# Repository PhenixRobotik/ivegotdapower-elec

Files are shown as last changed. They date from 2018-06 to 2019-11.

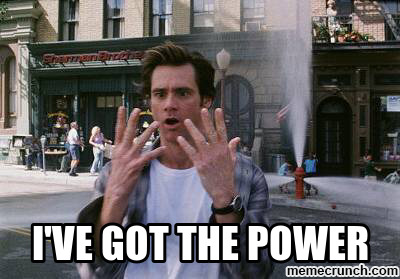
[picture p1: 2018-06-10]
ivegotdapower.jpg

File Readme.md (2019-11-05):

# IveGotDaPower, dépôt électronique

Carte alimentation de PhenixRobotik pour la base roulante TheySeeMeRolling.

<div class="alert alert-warning">
    #This project requires KiCAD 5.0 and is not compatible with previous versions (software and libraries).
</div>

# Features

* Dual power input with no-cut switch
  * Battery 6S (24V max)
  * Power supply

* Multiple power outputs
  * Power (direct, 6A)
  * Elec (7.5V ~3A)
  * USB (for Rpi, 2A)
  * …

* Voltage + current instrumentations

* CAN bus

# Idées

* stm32f3
* LiPoBipper (équilibrage) ? (ou direct sur la batterie == plus safe ?)

* Bouton d'arrêt d'urgence qui coupe la puissance moteurs ?

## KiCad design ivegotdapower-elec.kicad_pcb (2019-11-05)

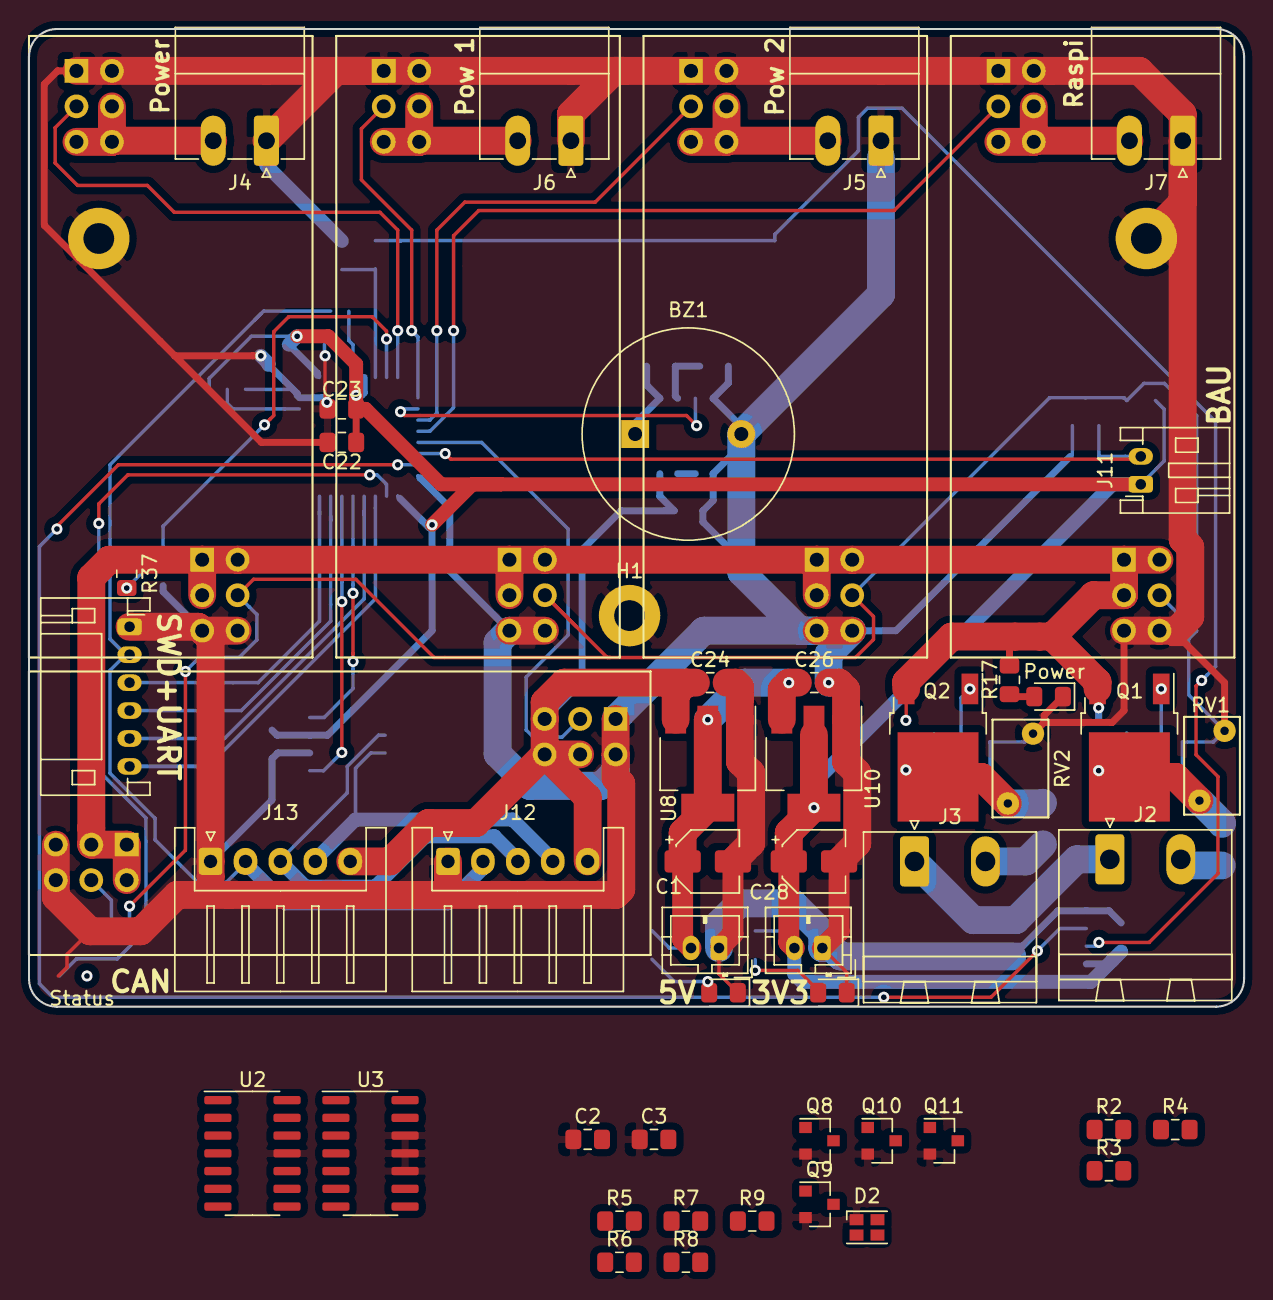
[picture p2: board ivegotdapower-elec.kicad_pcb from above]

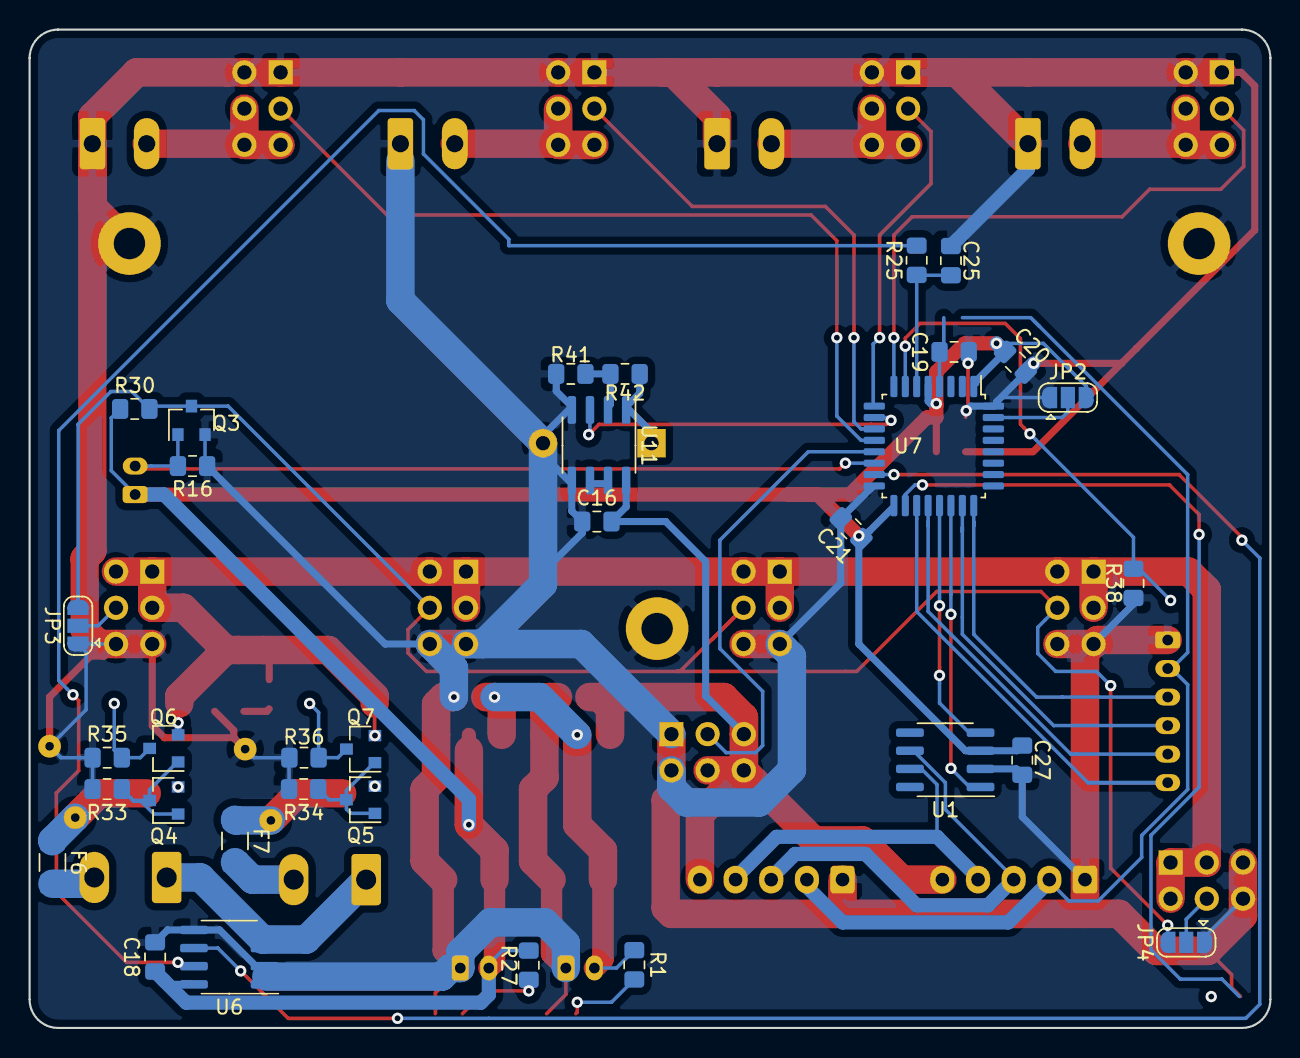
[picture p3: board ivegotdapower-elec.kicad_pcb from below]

Board: 2 copper layers, 87.0 x 70.0 mm, 88 parts (33 on the bottom side), 66 nets.

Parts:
B1, B2, B3, B4, B5: board_fille
BZ1: Buzzer; Buzzer_15x7.5RM7.6
C1, C28: 10uF; CP_Elec_4x5.4
C2, C3, C16, C18, C19, C20, C21, C23, C24, C25, C26, C27: 100nF; C_0805_2012Metric_Pad1.15x1.40mm_HandSolder
C22: 4.7uF; C_0805_2012Metric_Pad1.15x1.40mm_HandSolder
D1, D12, D16: LED; LED_0805_2012Metric_Pad1.15x1.40mm_HandSolder
D2: LED_ARGB; LED_Cree-PLCC4_2x2mm_CW
F6, F7: Fuse; Fuse_1206_3216Metric_Pad1.42x1.75mm_HandSolder
H1, H2, H3: MountingHole_Pad; MountingHole_2.2mm_M2_Pad
J1: Conn_Debug; JST_PH_S6B-PH-K_1x06_P2.00mm_Horizontal
J2: Conn_batt; PhoenixContact_MSTBA_2,5_2-G-5,08_1x02_P5.08mm_Horizontal
J3: Conn_alim; PhoenixContact_MSTBA_2,5_2-G-5,08_1x02_P5.08mm_Horizontal
J4: Conn_TSMR; PhoenixContact_MC_1,5_2-G-3.81_1x02_P3.81mm_Horizontal
J5: Conn_POW2; PhoenixContact_MC_1,5_2-G-3.81_1x02_P3.81mm_Horizontal
J6: Conn_POW1; PhoenixContact_MC_1,5_2-G-3.81_1x02_P3.81mm_Horizontal
J7: Conn_RPi; PhoenixContact_MC_1,5_2-G-3.81_1x02_P3.81mm_Horizontal
J8: Conn_+5V; JST_PH_B2B-PH-K_1x02_P2.00mm_Vertical
J10: Conn_+3.3V; JST_PH_B2B-PH-K_1x02_P2.00mm_Vertical
J11: Conn_bau; JST_PH_S2B-PH-K_1x02_P2.00mm_Horizontal
J12, J13: CAN_conn; JST_XH_S05B-XH-A_1x05_P2.50mm_Horizontal
JP2, JP3, JP4: Jumper_NC_Dual; SolderJumper-3_P1.3mm_Open_RoundedPad1.0x1.5mm
Q1, Q2: IRFR5305; TO-252-2
Q3, Q8, Q9, Q10, Q11: BSS138; SOT-23
Q4, Q5, Q6, Q7: MMBT2907A; SOT-23
R1, R17, R25, R27, R30, R33, R34, R35, R36, R41, R42: R; R_0805_2012Metric_Pad1.15x1.40mm_HandSolder
R2: 91; R_0805_2012Metric_Pad1.15x1.40mm_HandSolder
R3: 27; R_0805_2012Metric_Pad1.15x1.40mm_HandSolder
R4: 39; R_0805_2012Metric_Pad1.15x1.40mm_HandSolder
R5, R6, R7, R8, R9: 10k; R_0805_2012Metric_Pad1.15x1.40mm_HandSolder
R16: 1k; R_0805_2012Metric_Pad1.15x1.40mm_HandSolder
R37: 75k; R_0805_2012Metric_Pad1.15x1.40mm_HandSolder
R38: 15k; R_0805_2012Metric_Pad1.15x1.40mm_HandSolder
RV1, RV2: Varistor; RV_Disc_D7mm_W4mm_P5mm
U1: TCAN332; SOIC-8_3.9x4.9mm_P1.27mm
U2, U3: LM324; SOIC-14_3.9x8.7mm_P1.27mm
U6: ACS711xLCTR-12AB; SOIC-8_3.9x4.9mm_P1.27mm
U7: STM32F303K8Tx; LQFP-32_7x7mm_P0.8mm
U8: LD1117S50TR; SOT-223-3_TabPin2
U10: LD1117S33TR; SOT-223-3_TabPin2
U11: LM358; SOIC-8_3.9x4.9mm_P1.27mm

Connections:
+3V3: C18.1, C20.1, C21.1, C22.1, C23.1, C27.2, C28.1, J10.2, J11.1, JP2.3, R5.1, R6.1, R7.1, R8.1, R9.1, R27.1, R30.1, U1.3, U6.8, U7.1, U7.5, U7.17, U10.2
+5V: C1.1, C2.2, C3.2, C26.1, J8.2, R1.1, U2.4, U3.4, U8.2, U10.3
+7.5V: B2.10, B2.11, B2.12, C16.2, C24.1, J12.5, J13.5, U8.3, U11.8
/STM32/Buzzer: U7.10, U11.3
/STM32/CAN_RX: U1.4, U7.21
/STM32/CAN_TX: U1.1, U7.22
/STM32/RX_1: J1.5, U7.20
/STM32/TCK: J1.3, U7.24
/STM32/TMS: J1.4, U7.23
/STM32/TX_1: J1.6, U7.19
/STM32/mes_current: R25.1, U6.7
/STM32/mes_current_fault: U6.6, U7.15
/STM32/mes_protected_TSMR: U2.6, U2.7, U7.8
/STM32/mes_protected_logic: U3.6, U3.7, U7.13
/STM32/mes_protected_pow1: U2.8, U2.9, U7.9
/STM32/mes_protected_pow2: U2.13, U2.14, U7.11
/STM32/mes_protected_raw: U2.1, U2.2, U7.7
/STM32/mes_protected_rpi: U3.1, U3.2, U7.12
/STM32/mes_raw: R37.2, R38.1, U2.3
/STM32/reset_can: J12.2, J13.2, Q8.1, R5.2
/STM32/reset_logic/Reset_MCU: C19.1, Q9.3, Q11.3, R7.2, U7.4
/STM32/reset_swd: J1.2, Q10.1, R8.2
/buck/Logic_mes: B2.9, U3.5
/buck/Pow1_mes: B3.9, U2.10
/buck/Pow2_mes: B4.9, U2.12
/buck/RPi_mes: B1.9, U3.3
/buck/TSMR_mes: B5.9, U2.5
/buck/bau: J11.2, Q3.1, R16.1, U7.14
/buck/~on~-off: B3.4, B4.4, B5.4, JP3.3, JP4.3, Q3.3, R30.2
/power_selection/Valim+: F7.2, J3.2
/power_selection/Vbatt+: F6.2, J2.2
/power_selection/gnd_alims: J2.1, J3.1, U6.3, U6.4
GND: B1.5, B1.6, B1.7, B1.8, B2.5, B2.6, B2.7, B2.8, B3.5, B3.6, B3.7, B3.8, B4.5, B4.6, B4.7, B4.8, B5.5, B5.6, B5.7, B5.8, BZ1.2, C1.2, C2.1, C3.1, C16.1, C18.2, C19.2, C20.2, C21.2, C22.2, C23.2, C24.2, C25.1, C26.2, C27.1, C28.2, D1.1, D2.1, D12.1, D16.1, H1.1, H2.1, H3.1, J1.1, J4.1, J5.1, J6.1, J7.1, J8.1, J10.1, J12.1, J13.1, JP2.1, JP3.1, JP4.1, Q3.2, Q8.2, Q9.2, Q10.2, Q11.2, R16.2, R33.2, R34.2, R35.2, R36.2, R38.2, R41.1, RV1.2, RV2.2, U1.2, U2.11, U3.10, U3.11, U3.12, U6.1, U6.2, U6.5, U7.16, U7.32, U8.1, U10.1, U11.4, U11.5
IN: B1.1, B1.2, B1.3, B2.1, B2.2, B2.3, B3.1, B3.2, B3.3, B4.1, B4.2, B4.3, B5.1, B5.2, B5.3, Q1.3, Q2.3, Q6.2, Q7.2, R17.1, R37.1
unnamed: B1.4, JP3.2
unnamed: B1.10, B1.11, B1.12, J7.2
unnamed: B2.4, JP4.2
unnamed: B3.10, B3.11, B3.12, J6.2
unnamed: B4.10, B4.11, B4.12, J5.2
unnamed: B5.10, B5.11, B5.12, J4.2
unnamed: BZ1.1, R42.2, U11.1
unnamed: C25.2, R25.2, U7.6
unnamed: D1.2, R1.2
unnamed: D2.2, R2.2
unnamed: D2.3, R3.2
unnamed: D2.4, R4.2
unnamed: D12.2, R17.2
unnamed: D16.2, R27.2
unnamed: F6.1, Q1.2, Q4.2, RV1.1
unnamed: F7.1, Q2.2, Q5.2, RV2.1
unnamed: J12.3, J13.3, U1.6
unnamed: J12.4, J13.4, U1.7
unnamed: JP2.2, U7.31
unnamed: Q1.1, Q6.3, R35.1
unnamed: Q2.1, Q7.3, R36.1
unnamed: Q4.1, Q4.3, Q6.1, R33.1
unnamed: Q5.1, Q5.3, Q7.1, R34.1
unnamed: Q8.3, Q9.1, R6.2
unnamed: Q10.3, Q11.1, R9.2
unnamed: R2.1, U7.28
unnamed: R3.1, U7.29
unnamed: R4.1, U7.30
unnamed: R41.2, R42.1, U11.2
unnamed: U3.8, U3.9
unnamed: U3.13, U3.14
unnamed: U11.6, U11.7

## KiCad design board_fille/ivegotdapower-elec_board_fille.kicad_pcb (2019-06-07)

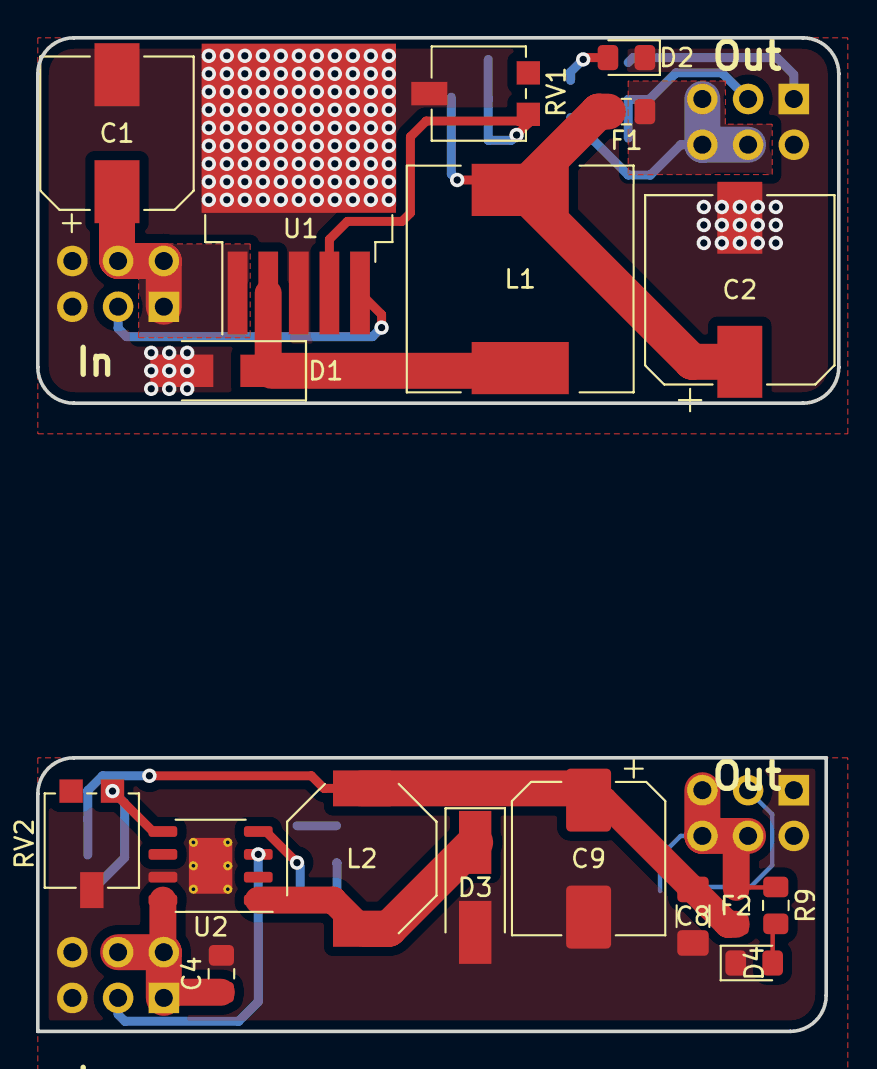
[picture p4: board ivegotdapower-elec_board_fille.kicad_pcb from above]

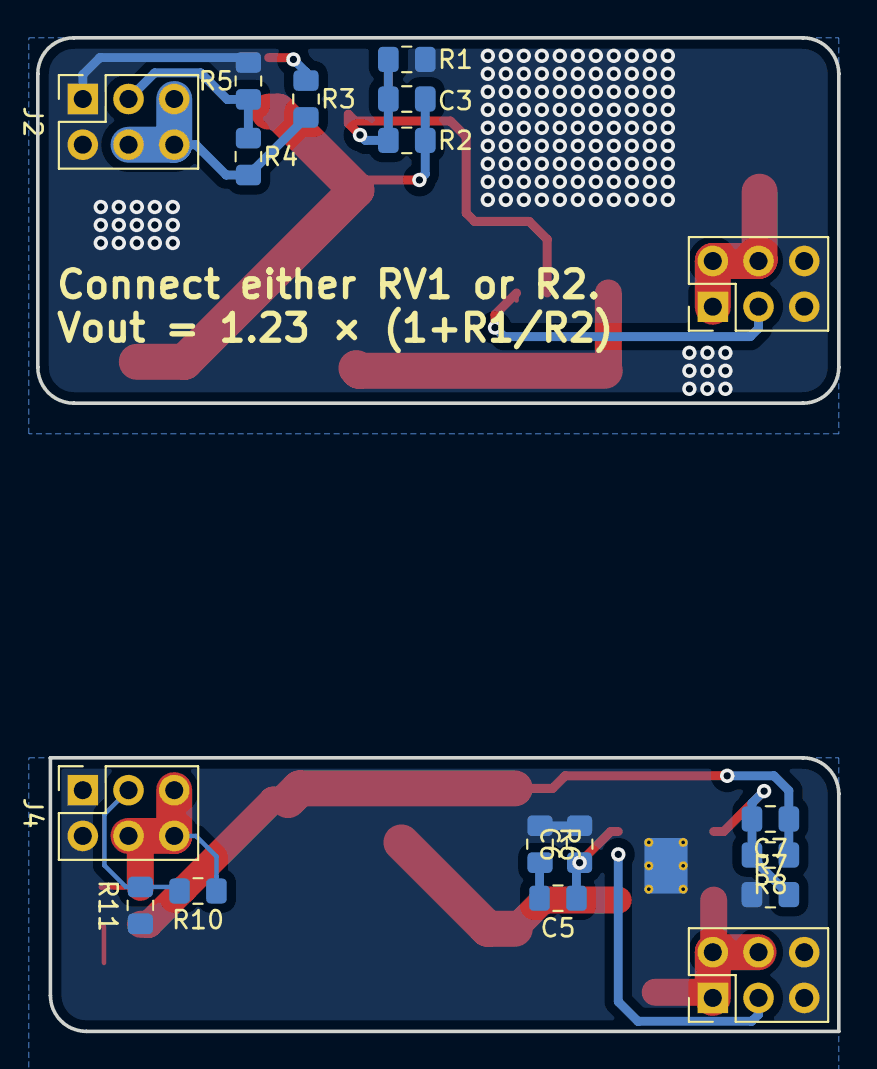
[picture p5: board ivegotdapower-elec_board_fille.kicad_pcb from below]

Board: 2 copper layers, 44.5 x 55.2 mm, 36 parts (18 on the bottom side), 15 nets.

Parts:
C1: 100uF; CP_Elec_8x10
C2: 220uF; CP_Elec_10x10
C3, C7: 15nF; C_0805_2012Metric_Pad1.15x1.40mm_HandSolder
C4: 10uF; C_0805_2012Metric_Pad1.15x1.40mm_HandSolder
C5: 22nF; C_0805_2012Metric_Pad1.15x1.40mm_HandSolder
C6: 220pF; C_0805_2012Metric_Pad1.15x1.40mm_HandSolder
C8: C; C_1206_3216Metric_Pad1.42x1.75mm_HandSolder
C9: 330uF; CP_Elec_8x10
D1, D3: D_Schottky 3A 40V; D_SMA_Handsoldering
D2, D4: LED; LED_0805_2012Metric_Pad1.15x1.40mm_HandSolder
F1, F2: Fuse; Fuse_0805_2012Metric_Pad1.15x1.40mm_HandSolder
J1, J3: Conn_02x03_Odd_Even; PinHeader_2x03_P2.54mm_Vertical
J2, J4: Conn_02x03_Odd_Even; PinSocket_2x03_P2.54mm_Vertical
L1: 33uH; L_12x12mm_H8mm
L2: 15uH; L_Bourns-SRU8043
R1, R7: 1k; R_0805_2012Metric_Pad1.15x1.40mm_HandSolder
R2, R8: 3.1k; R_0805_2012Metric_Pad1.15x1.40mm_HandSolder
R3, R4, R5, R9, R10, R11: R; R_0805_2012Metric_Pad1.15x1.40mm_HandSolder
R6: 4k7; R_0805_2012Metric_Pad1.15x1.40mm_HandSolder
RV1, RV2: R_POT; Potentiometer_Vishay_TS53YL_Vertical
U1: LM2596S-ADJ; TO-263-5_TabPin3
U2: L5973D; HSOP-8-1EP_3.9x4.9mm_P1.27mm_EP2.41x3.1mm_ThermalVias

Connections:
/Power_Input: C1.1, C4.1, J1.1, J1.2, J1.4, J3.1, J3.2, J3.4, U1.1, U2.8
/Power_Output: F1.1, F2.1, J2.4, J2.5, J2.6, J4.4, J4.5, J4.6, R3.1, R4.1, R9.1, R10.1
/on-off: J1.3, J3.3, U1.5, U2.3
/voltage_measure: J2.3, J4.3, R4.2, R5.1, R10.2, R11.1
GND: C1.2, C2.2, C4.2, C6.2, C8.2, C9.2, D1.2, D2.1, D3.2, D4.1, J1.5, J1.6, J2.1, J2.2, J3.5, J3.6, J4.1, J4.2, R1.1, R5.2, R6.1, R7.1, R11.2, RV1.2, RV2.2, U1.3, U2.7, U2.9
unnamed: C2.1, C3.1, F1.2, L1.2, R2.1
unnamed: C3.2, R1.2, R2.2, RV1.3, U1.4
unnamed: C5.1, C6.1, U2.4
unnamed: C5.2, R6.2
unnamed: C7.1, C8.1, C9.1, F2.2, L2.2, R8.1
unnamed: C7.2, R7.2, R8.2, RV2.3, U2.5
unnamed: D1.1, L1.1, U1.2
unnamed: D2.2, R3.2
unnamed: D3.1, L2.1, U2.1
unnamed: D4.2, R9.2

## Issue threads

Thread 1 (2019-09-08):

Problème protection mesure

42Max42, 2019-09-08:
ajouter une protection de sur-tension sur la mesure du stm32 pour éviter un accident

Salamandar, 2019-11-05:
Fixed by a2e53cf.

Closed 2019-11-05.

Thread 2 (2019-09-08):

Problème de sens des cartes filles

42Max42, 2019-09-08:
ajouter des détrompeurs pour éviter un branchement en sens inverse

Salamandar, 2019-09-08:
Alrebdy fixed on Master, need backport on existing hardware.

Salamandar, 2019-11-05:
Bon on peut fermer peut-être…

Closed 2019-11-05.

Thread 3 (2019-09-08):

Reset sur le CAN

42Max42, 2019-09-08:
corriger le problème de reset

Salamandar, 2019-09-08:
Mais alors on fait quoi ? On ne le relie pas du tout ? On met des diodes ?
Je suis d'avis comme on l'avait déjà évoqué d'avoir un message de soft-reset sur le CAN qui doit être interprété par le firmware.

Salamandar, 2019-11-05:
Backported the fix with 0896a17

Closed 2019-11-05.

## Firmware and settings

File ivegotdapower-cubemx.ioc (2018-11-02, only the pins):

Mcu.UserName=STM32F303K8Tx
PA0.GPIO_Label=ADC_IN1 [SENSE]
PA0.Signal=ADC1_IN1
PA1.GPIO_Label=ADC1_IN2 [RPI]
PA1.Signal=ADC1_IN2
PA10.Signal=USART1_RX
PA11.Signal=CAN_RX
PA12.Signal=CAN_TX
PA13.Signal=SYS_JTMS-SWDIO
PA14.Signal=SYS_JTCK-SWCLK
PA2.GPIO_Label=ADC1_IN3 [RAW]
PA2.Signal=ADC1_IN3
PA3.GPIO_Label=ADC1_IN4 [LOGIC]
PA3.Signal=ADC1_IN4
PA4.GPIO_Label=DAC1_OUT1 [BUZZER]
PA4.Signal=COMP_DAC11_group
PA5.GPIO_Label=ADC2_IN2 [POW1]
PA5.Signal=ADC2_IN2
PA6.GPIO_Label=ADC2_IN3 [POW2]
PA6.Signal=ADC2_IN3
PA7.GPIO_Label=ADC2_IN4 [TSMR]
PA7.Signal=ADC2_IN4
PA8.GPIO_Label=LED
PA8.Signal=GPIO_Output
PA9.Signal=USART1_TX
PB0.GPIO_Label=BAU
PB0.Signal=GPIO_Input
PB1.GPIO_Label=FAULT
PB1.Signal=GPIO_Input

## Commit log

2018-06-11 Add gitignore, add some schematics
    [ivegotdapower-elec.sch]
2018-06-13 Add power sources switch
    [ivegotdapower-elec.sch]
2018-06-17 move, add input protections
    [ivegotdapower-elec.sch]
2018-06-17 Add outline for 5×5cm / 10×5cm
    [ivegotdapower-elec.kicad_pcb]
2018-06-18 Footprint Association
    [ivegotdapower-elec.sch]
2018-06-18 Change LTC4353 symbol (MSOP), change MOSFET symbols and footprints.
    [ivegotdapower-elec.sch]
2018-06-18 Add most of interesting components.
    [ivegotdapower-elec.kicad_pcb]
2018-07-11 Add can connectors, power input/output connectors. Fix labels/power symbols. Remove schottky diodes, use NMOS on base instead.
    [ivegotdapower-elec.sch]
2018-07-11 Add connectors, power footprints. Not sure of all footprints.
    [ivegotdapower-elec.kicad_pcb]
2018-07-11 Small reorganization. There is space left for stm32.
    [ivegotdapower-elec.kicad_pcb]
2018-10-03 power regulators added
    [STM32.sch, buck.sch, ivegotdapower-elec.sch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]
2018-10-03 +5V and +3.3V added in case of PLS and connector for power selection
    [STM32.sch, ivegotdapower-elec.sch, power_selection.sch]
2018-10-03 Reorganize buck
    [STM32.sch, buck.sch, ivegotdapower-elec.sch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]
2018-10-03 Set footprints, cleanup PCB of old componnents
    [STM32.sch, buck.sch, ivegotdapower-elec.kicad_pcb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]
2018-10-04 buzzer and mes
    [STM32.sch, buck.sch, ivegotdapower-elec.sch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]
2018-10-04 varistor added
    [power_selection.sch]
2018-10-08 Add daughter power board
    [ivegotdapower-elec.kicad_pcb, ivegotdapower-elec.sch]
2018-10-09 fixed ideal diode
    [power_selection.sch]
2018-10-09 cleanup, finished design
    [ivegotdapower-elec.kicad_pcb, ivegotdapower-elec.sch]
2018-10-09 fixed bad connexion
    [power_selection.sch]
2018-10-10 very small changes in fille
    [ivegotdapower-elec.kicad_pcb]
2018-10-10 Add board_fille libraries
2018-10-10 level translation
    [STM32.sch, buck.sch, ivegotdapower-elec.sch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]
2018-10-24 jumper error corrected
    [ivegotdapower-elec.kicad_pcb, ivegotdapower-elec.sch]
2018-10-24 power routed
    [STM32.sch, buck.sch, ivegotdapower-elec.kicad_pcb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]
2018-10-25 update board_fille
    [buck.sch, ivegotdapower-elec.kicad_pcb, ivegotdapower-elec.sch]
2018-10-25 bords ronds
    [ivegotdapower-elec.kicad_pcb]
2018-11-02 Update schematics
    [STM32.sch, buck.sch, ivegotdapower-elec.sch]
2018-11-02 Placement and routing done
    [ivegotdapower-elec.kicad_pcb]
2018-11-02 Fixed phenix_kicad name
    [STM32.sch, ivegotdapower-elec.sch, power_selection.sch]
2018-11-02 Improvements on GND nets
    [ivegotdapower-elec.kicad_pcb]
2018-11-04 Sérigraphie
    [ivegotdapower-elec.kicad_pcb]
2018-11-04 Sérigraphies
    [ivegotdapower-elec.kicad_pcb]
2018-11-05 Silkscreen, better pcb
    [ivegotdapower-elec.kicad_pcb]
2018-11-05 Connect mountholes to GND, silkscreen
    [STM32.sch, buck.sch, ivegotdapower-elec.kicad_pcb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]
2018-11-05 Board cleanup, reorganize
    [STM32.sch, ivegotdapower-elec.kicad_pcb, ivegotdapower-elec.sch]
2018-11-05 small cleanup
    [ivegotdapower-elec.kicad_pcb]
2018-11-05 Moved MC connectors
    [ivegotdapower-elec.kicad_pcb]
2018-11-07 Changed LED footprints
    [STM32.sch, buck.sch, ivegotdapower-elec.kicad_pcb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]
2018-11-07 Changed fuse footprint
    [ivegotdapower-elec.kicad_pcb, power_selection.sch]
2018-11-09 some weird changes.
    [ivegotdapower-elec.kicad_pcb]
2018-11-12 Rename sub-board
    [ivegotdapower-elec_board_fille.kicad_pcb, ivegotdapower-elec_board_fille.sch]
2019-06-04 Add potentiometer to board. Move SMD further apart.
    [ivegotdapower-elec_board_fille.kicad_pcb, ivegotdapower-elec_board_fille.sch]
2019-06-05 add text below pcb
    [ivegotdapower-elec_board_fille.kicad_pcb]
2019-06-07 Add possible variant for board fille
    [ivegotdapower-elec_board_fille.kicad_pcb, ivegotdapower-elec_board_fille.sch]
2019-11-05 Refactoring. Add protection (OpAmps) on analog measures
    [STM32.sch, buck.sch, can_and_supply.sch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]
2019-11-05 Backport Bss138-powered reset separation
    [STM32.sch, buck.sch, can_and_supply.sch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]
2019-11-05 Rewrite board_fille symbol
    [buck.sch, power_selection.sch, reset_logic.sch]
2019-11-05 Fix libs
    [STM32.sch, buck.sch, can_and_supply.sch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]
